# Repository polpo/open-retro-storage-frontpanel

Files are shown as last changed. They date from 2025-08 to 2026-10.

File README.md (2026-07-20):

# Open Retro Storage Front Panel

A physical control and web interface for retro storage emulator projects including [PicoIDE](https://github.com/polpo/picoide) and [BlueSCSI](https://github.com/BlueSCSI/BlueSCSI-v2), based on the ESP32-C3 microcontroller.

PicoIDE variant of the enclosure

BlueSCSI variant of the enclosure

## Overview

The Open Retro Storage Front Panel provides a user-friendly interface for browsing, selecting, and managing drive images for storage emulators live on the device. It features:

- **SPI or I2C (Qwiic) connection to main board**
- **SPI OLED Display**: 128x64 1.3" screen for menu navigation and status display
- **4-Way Navigation**: Physical buttons for browsing drive images and settings
- **WiFi Interface**: Web-based control for changing drive images, adjusting settings, uploading new images, and firmware updates
- **3.5" Drive Bay Enclosure**: Designed for internal or external-facing mounting in standard drive bays

## Project Structure

```
open-retro-storage-frontpanel/
├── sw-frontpanel/       # Firmware source code
├── hw-frontpanel-3.5/   # PCB hardware design
└── enclosure/           # 3D printable enclosure design
```

### sw-frontpanel

ESP32-C3 firmware built with the ESP-IDF SDK (v5.5.1+).

**Features:**
- SPI or I2C (Qwiic) communication with host storage emulator
- Menu system for drive image browsing and selection
- WiFi client and access point modes with mDNS
- Embedded web server with REST API
- OTA firmware updates with SHA256 verification
- WS2812B addressable LED support
- Screen saver, auto-dim, or auto-off to preserve OLED display life

### hw-frontpanel-3.5

KiCad design files for the front panel PCB.

frontpanel-top frontpanel-bottom

**Main components:**
- ESP32-C3-MINI-1 module
- SH1107 1.3" OLED display (SPI interface)
- SK6812MINI-E (WS2812 compatible) addressable RGB LED
- Navigation buttons (either 1-piece silicone rubber dome or plastic button caps w/ individual domes)
- JST-SH connectors for QWIIC/I2C communication with host, external activity LED input, and development debugging, 0.5mm FFC connector for SPI communication with host, and Tag-Connect footprint for initial programming in production

Connector pinouts:

SPI (0.5mm FFC, 12 pin):

| Pin | Function |
|-----|---|
| 1 | Activity LED in |
| 2 | GND |
| 3 | SPI CS |
| 4 | GND |
| 5 | SPI CLK |
| 6 | GND |
| 7 | SPI RX (MISO) |
| 8 | GND |
| 9 | SPI TX (MOSI) |
| 10  | GND |
| 11  | +3.3V |
| 12  | +3.3V |

I2C/Qwiic (JST-SH, 4 pin):

| Pin | Function |
|-----|---|
| 1 | GND|
| 2 | +3.3V |
| 3 | SDA |
| 4 | SCL |

ACT (JST-SH, 2 pin):

| Pin | Function |
|-----|---|
| 1 | Activity LED in |
| 2 | GND |

Production files for JLCPCB assembly are included in `jlcpcb/production_files/`.

### enclosure

FreeCAD design for a 3.5" drive bay enclosure with STEP and STL exports for 3D printing.

**Included parts:**
- Main enclosure body
- Button caps
- Light pipe for activity/status LED
- Silicone button option

## Web Interface

The front panel hosts a web interface accessible at `http://picoide.local` (or via IP address) providing:

- Current drive image status
- Directory browsing
- File upload/download
- Config .ini file editing
- Image selection/ejection
- Firmware status and updates

## Licensing

| Component | License |
|---|---|
| sw-frontpanel | [GPL-2.0-only](sw-frontpanel/LICENSE) |
| hw-frontpanel-3.5 | [CERN-OHL-S-2.0](hw-frontpanel-3.5/LICENSE) |
| enclosure | [CERN-OHL-S-2.0](enclosure/LICENSE) |

## Credits

- Firmware by Ian Scott in collaboration with Eric Helgeson.
- Board design by Ian Scott with input from Jason Merrill.
- Enclosure by Jason Merrill.

## Open source components

- [ESP-IDF](https://github.com/espressif/esp-idf) development framework for ESP32
- [u8g2](https://github.com/olikraus/u8g2) graphics library for OLED
- [u8g2-hal-esp-idf](https://github.com/mkfrey/u8g2-hal-esp-idf) u8g2 HAL layer for ESP-IDF

## Contributing

Contributions are welcome! Please ensure any firmware contributions maintain GPL v2 compatibility and hardware contributions are compatible with CERN-OHL-S v2.

## Building the firmware

Make sure you check out this repository with submodules. If it's already checked out, `git submodule update --init` will fetch them. See [sw-frontpanel/BUILD.md](sw-frontpanel/BUILD.md) for detailed instructions including configuration of target type (PicoIDE/BlueSCSI, SPI/I2C).

## Programming the firmware

For normal firmware upgrades, the front panel can be upgraded via the web interface. But if you're building from scratch or need to recover a bricked unit, you'll need to program the ESP32-C3 by UART bootloader.

There are two footprints on the board that can be used to program it: J4 (prog) and J6 (dbg). J4 is a [Tag-Connect](https://www.tag-connect.com/) footprint, using the [TC2030-IDC-NL](https://www.tag-connect.com/product/tc2030-idc-nl) connector. The pinout matches the 6-pin connector on the [Espressif ESP-PROG 2](https://docs.espressif.com/projects/esp-dev-kits/en/latest/other/esp-prog-2/user_guide.html) programmer:

| Pin | Function |
|-----|---|
| 1 | EN (RTS) |
| 2 | +3.3V |
| 3 | TX |
| 4 | GND |
| 5 | RX |
| 6 | IO0 (DTR) |

J6 is a JST SH 5-pin connector with the following pinout (pins numbered ascending left to right):

| Pin | Function |
|-----|---|
| 1 | GND |
| 2 | RX |
| 3 | TX |
| 4 | EN (RTS) |
| 5 | IO0 (DTR) |

Note that J6 does not carry +3.3V so you'll have to provide it on the SPI or I2C (QWIIC) connector.

Note that the TX signal is shared with the LED input, so if it is driven via the SPI connector programming will not be possible.

Use `esptool` or `esp.py program` to program the firmware after it has been built.

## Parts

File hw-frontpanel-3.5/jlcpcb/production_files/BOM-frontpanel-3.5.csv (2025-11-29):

Comment | Designator | Footprint | LCSC | Quantity
100K | R1 | R_0402_1005Metric | C25741 | 1
100nF | C5,C6 | C_0402_1005Metric | C307331 | 2
100uF | C12 | C_1206_3216Metric | C96123 | 1
10K | R10,R4,R5,R6,R7 | R_0402_1005Metric | C25744 | 5
10uF | C1,C4,C9 | C_0603_1608Metric | C96446 | 3
10uH | L1 | L_0805_2012Metric | C1046 | 1
15K | R2 | R_0402_1005Metric | C25756 | 1
1N5819WS | D2 | D_SOD-323 | C191023 | 1
1uF | C10,C11,C2,C3 | C_0402_1005Metric | C52923 | 4
2.2K | R8,R9 | R_0402_1005Metric | C25879 | 2
33 | R11,R12,R13 | R_0402_1005Metric | C25105 | 3
390K | R3 | R_0402_1005Metric | C25782 | 1
4.7uF | C7,C8 | C_0603_1608Metric | C19666 | 2
ESP32-C3-MINI-1 | U3 | ESP32-C6-MINI-1 | C2838502 | 1
LED | J3 | JST_SH_BM02B-SRSS-TB_1x02-1MP_P1.00mm_Vertical | C7433438 | 1
LM809 | U2 | SOT-23 | C5379074 | 1
MT3540 | U1 | SOT-23-5 | C181744 | 1
QWIIC | J2 | JST_SH_BM04B-SRSS-TB_1x04-1MP_P1.00mm_Vertical | C7433440 | 1
SK6812MINI-E_C5149201 | LED1 | LED-SMD_L3.2-W2.8-LS5.9_SK6812MINI-E | C5149201 | 1
SPI | J1 | FPC-SMD_12P-L11.5-W2.0-P0.50 | C11069 | 1

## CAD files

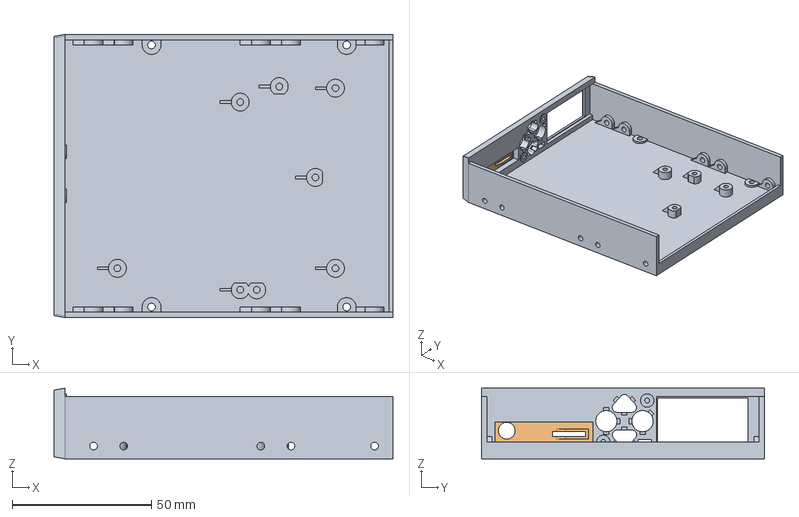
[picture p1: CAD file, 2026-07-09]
enclosure/PicoIDE 3.5 Enclosure.step
121.6 x 101.6 x 25.3 mm
PicoIDE Enclosure
PicoIDE Logo

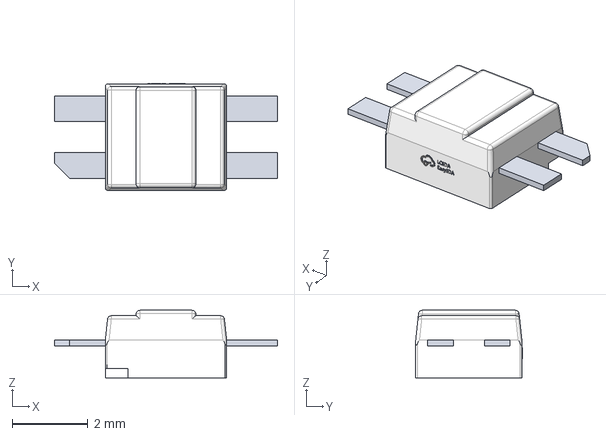
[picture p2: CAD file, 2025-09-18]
hw-frontpanel-3.5/models/LED-SMD_L3.2-W2.8-LS5.9_SK6812MINI-E~LED-SMD_L3.2-W2.8-LS5.9_SK6812MINI-E~0LKI.step
5.88 x 2.81 x 1.78 mm

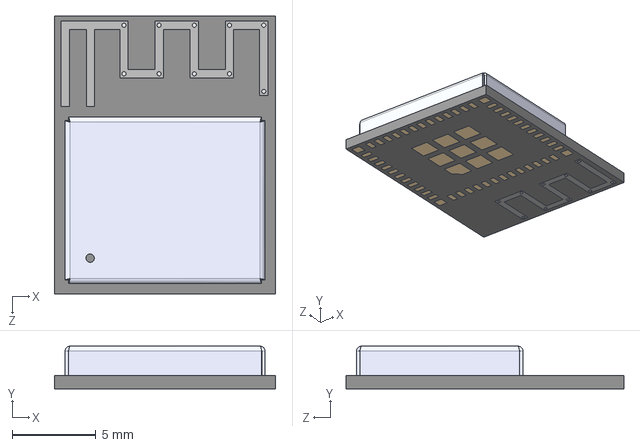
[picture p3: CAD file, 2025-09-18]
hw-frontpanel-3.5/models/ESP32-C6-MINI-1-N4.STEP
13.2 x 2.55 x 16.6 mm

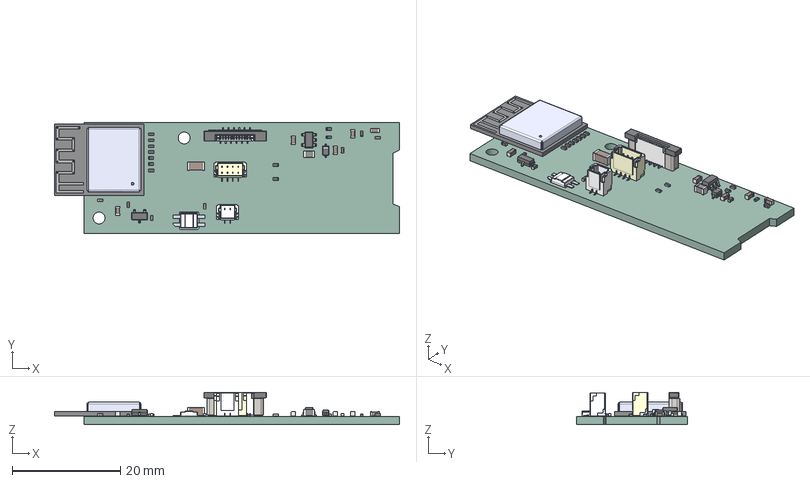
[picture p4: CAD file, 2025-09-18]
hw-frontpanel-3.5/models/frontpanel-3.5-mini.step
63.8 x 20.5 x 5.97 mm
R_0402_1005Metric x 13
LED-SMD_L3.2-W2.8-LS5.9_SK6812MINI-E~LED-SMD_L3.2-W2.8-LS5.9_ SK6812MINI-E~0LKI
C_0402_1005Metric x 5
C_0603_1608Metric x 5
SOT-23-5
D_SOD-323
BM04B-SRSS-TB
L_0805_2012Metric
SOT-23
FPC-SMD_12P-L11.5-W2.0-P0.50~FPC-SMD_12P-L11.6-W2.0-H4.4-P0.50~1kdR
ESP32-C6-MINI-1-N4
C_1206_3216Metric
BMxxB-SRSS-TB(LF)(SN)_02
frontpanel-3.5_PCB

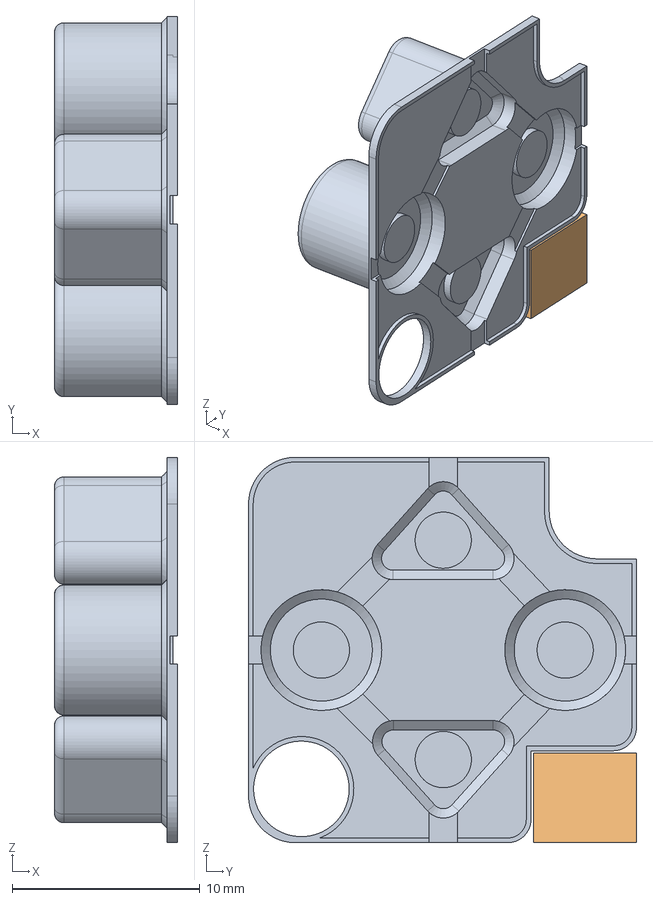
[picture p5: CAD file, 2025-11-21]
enclosure/PicoIDE 3.5 Enclosure-Silicone Buttons.step
6.56 x 20.7 x 20.5 mm

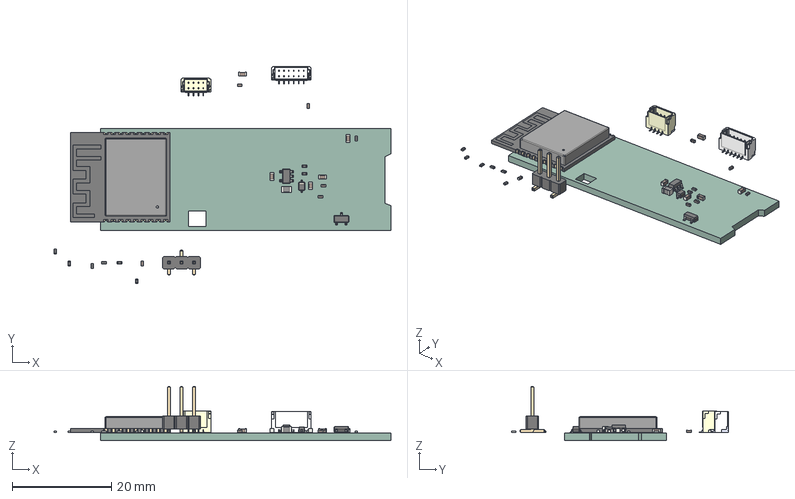
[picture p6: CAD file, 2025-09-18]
hw-frontpanel-3.5/models/frontpanel-3.5-cursed.step
67.8 x 43.8 x 10.9 mm
R_0402_1005Metric x 9
C_0402_1005Metric x 5
C_0603_1608Metric x 5
SOT-23-5
D_SOD-323
BM04B-SRSS-TB
L_0805_2012Metric
SOT-23
BMxxB-SRSS-TB(LF)(SN)_06
ESP32-C3-WROOM-02
PinHeader_1x03_P2.54mm_Vertical_SMD_Pin1Left
frontpanel-3.5_PCB

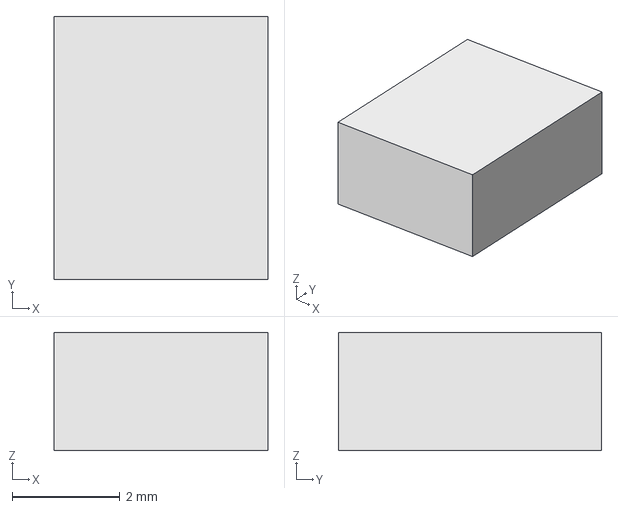
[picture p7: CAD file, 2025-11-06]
enclosure/PicoIDE 3.5 Enclosure-Light Pipe.step
3.98 x 4.90 x 2.20 mm

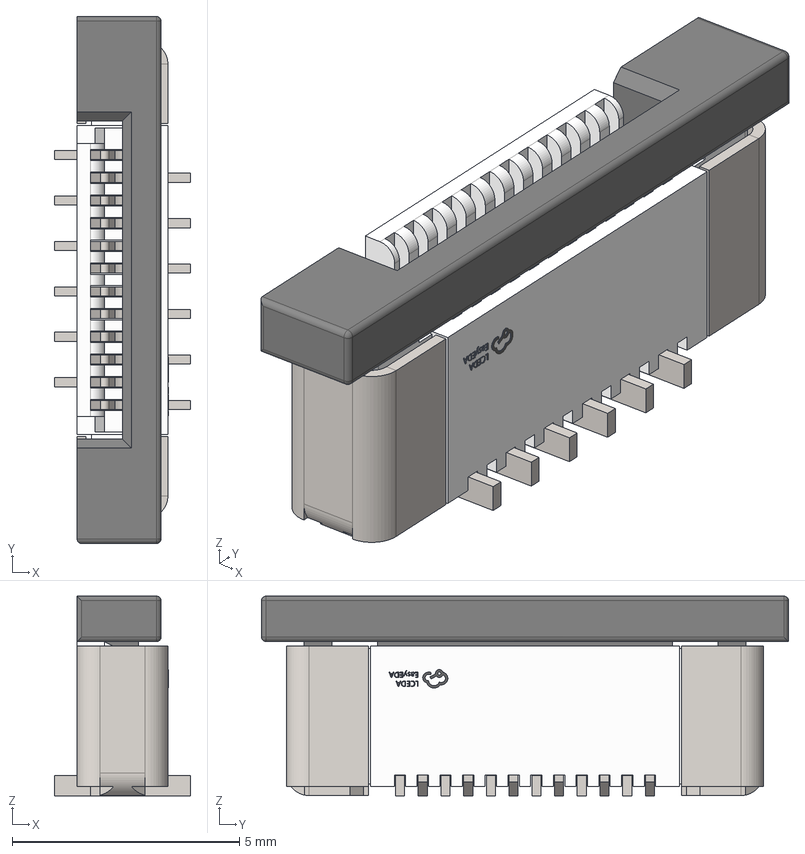
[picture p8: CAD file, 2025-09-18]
hw-frontpanel-3.5/models/AFC11-S12ICC-00.step
3.00 x 11.6 x 4.39 mm

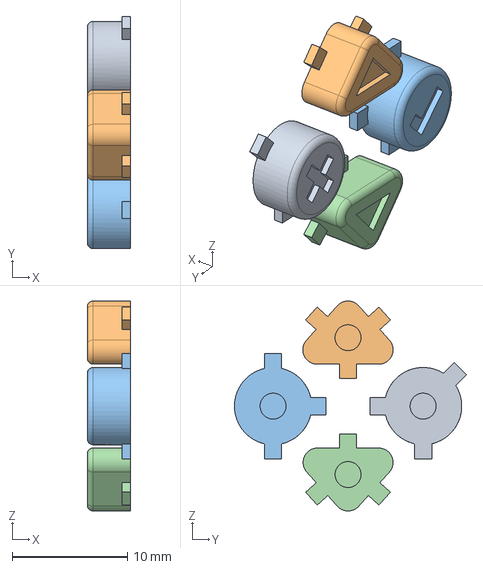
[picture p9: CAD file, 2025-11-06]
enclosure/PicoIDE 3.5 Enclosure-Buttons.step
3.75 x 20.1 x 18.2 mm

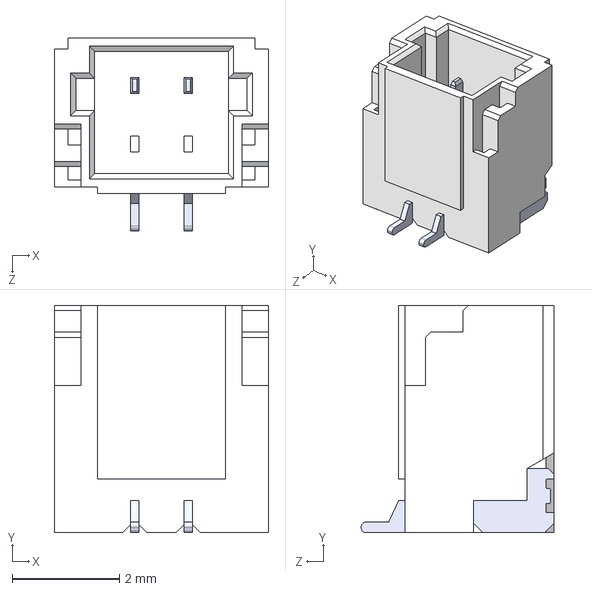
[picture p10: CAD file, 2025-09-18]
hw-frontpanel-3.5/models/BM02B-SRSS-TB.STEP
4.00 x 4.25 x 3.60 mm

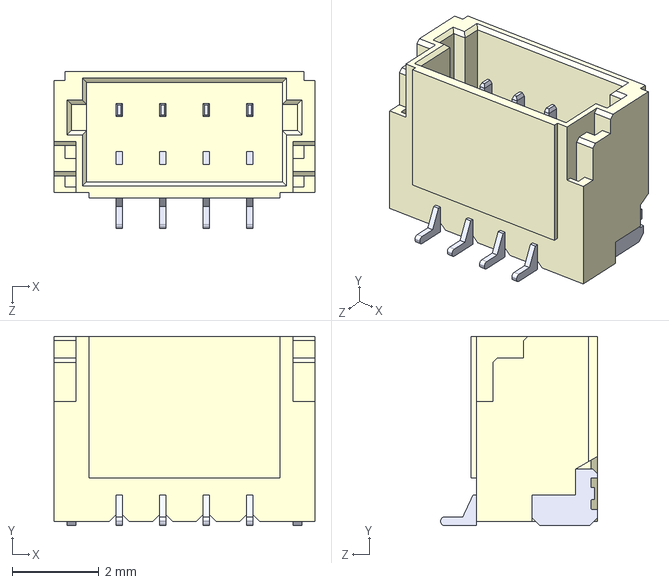
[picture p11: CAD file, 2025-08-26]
hw-frontpanel-3.5/models/BM04B-SRSS-TB.STEP
6.00 x 4.35 x 3.60 mm

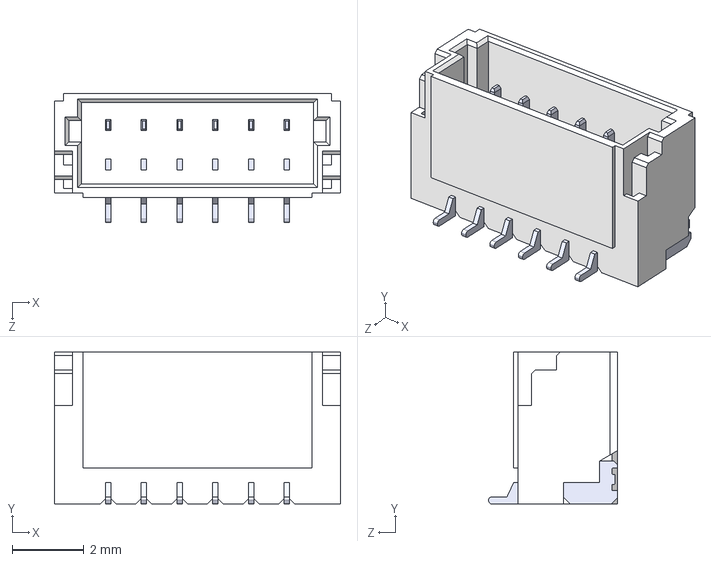
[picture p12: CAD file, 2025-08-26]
hw-frontpanel-3.5/models/BM06B-SRSS-TB.STEP
8.00 x 4.25 x 3.60 mm

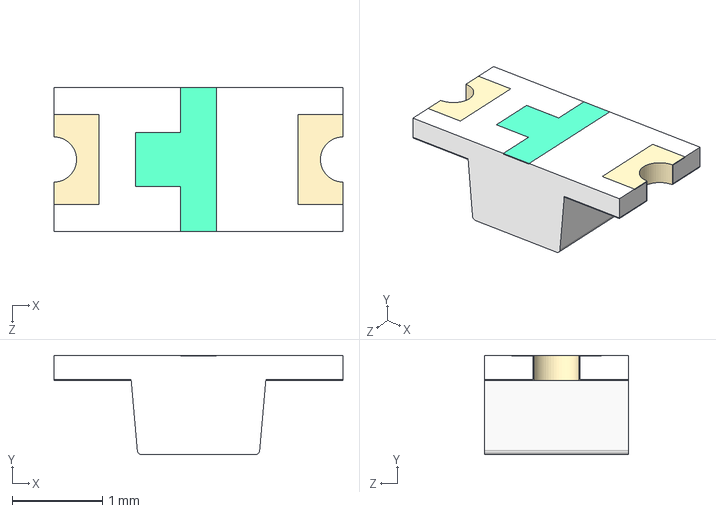
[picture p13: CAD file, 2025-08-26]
hw-frontpanel-3.5/models/LTST-C230KGKT.step
3.20 x 1.10 x 1.60 mm

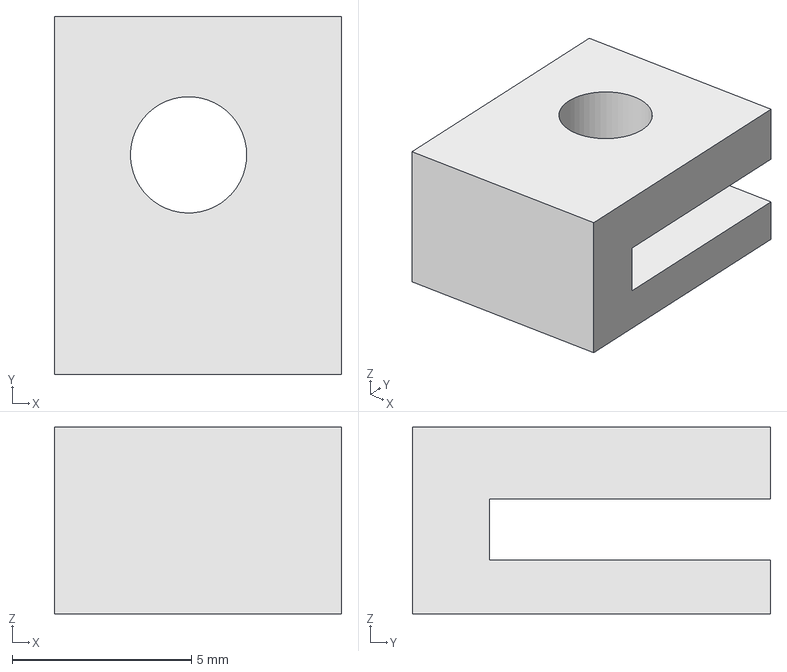
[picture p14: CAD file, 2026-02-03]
enclosure/BlueSCSI Screw Adapter.step
8.00 x 9.99 x 5.21 mm

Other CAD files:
enclosure/BlueSCSI 3.5 Enclosure.step
enclosure/BlueSCSI 3.5 Enclosure.stl
enclosure/BlueSCSI Screw Adapter.stl
enclosure/PicoIDE 3.5 Enclosure-Buttons.stl
enclosure/PicoIDE 3.5 Enclosure-Light Pipe.stl
enclosure/PicoIDE 3.5 Enclosure-Silicone Buttons.stl
enclosure/PicoIDE 3.5 Enclosure.FCStd
enclosure/PicoIDE 3.5 Enclosure.stl

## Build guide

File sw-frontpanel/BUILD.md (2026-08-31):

# Building the firmware

The front-panel firmware targets the ESP32-C3 and is built with ESP-IDF
(v5.5.2). It ships as two product variants — **PicoIDE** and **BlueSCSI** —
selected at configure time via ESP-IDF `sdkconfig` defaults. There is no
interactive `menuconfig` step required to pick the product.

The **host transport** (SPI vs I2C) is detected at runtime on BlueSCSI: one
binary covers **v2** (I2C) and **Ultra / Ultra Wide** (SPI), and the panel
remembers the last transport a live main board answered on in NVS. PicoIDE is
always SPI. For debugging, `menuconfig` can force a single transport
(`HOST_TRANSPORT` choice).

## Development environment

On NixOS / with Nix, a dev shell pins ESP-IDF and the web-asset build
dependencies. Prefix the build commands below with `nix develop --command`,
or enter the shell first:

```bash
nix develop          # flake-based (preferred)
# or: nix-shell       # shell.nix
```

Without Nix, follow the upstream
[ESP-IDF toolchain setup](https://docs.espressif.com/projects/esp-idf/en/stable/esp32c3/get-started/)
and run the same `idf.py` commands.

## Selecting a product

The product is chosen by layering a per-product defaults file on top of the
common `sdkconfig.defaults`:

| Product | Defaults files | Firmware output |
| --- | --- | --- |
| PicoIDE | `sdkconfig.defaults.picoide` | `picoide-frontpanel.bin`  |
| BlueSCSI (v2 / Ultra, one image) | `sdkconfig.defaults.bluescsi`  | `bluescsi-frontpanel.bin` |

Build each product into its **own build directory** (`-B build-<product>`) with
its **own `sdkconfig`** (`-DSDKCONFIG=build-<product>/sdkconfig`). Both flags are
required to keep the products isolated — see the warning below.

> Note: builds prior to the unified BlueSCSI image used
> `build-bluescsi-ultra` / `build-bluescsi-v2` directories. Those pin the old
> transport symbols in their `sdkconfig` — don't reuse them; build into a fresh
> `build-bluescsi`.

### BlueSCSI

```bash
idf.py -B build-bluescsi \
  -DSDKCONFIG=build-bluescsi/sdkconfig \
  -DSDKCONFIG_DEFAULTS="sdkconfig.defaults;sdkconfig.defaults.bluescsi" \
  build
```

Output: `build-bluescsi/bluescsi-frontpanel.bin`

### PicoIDE

```bash
idf.py -B build-picoide \
  -DSDKCONFIG=build-picoide/sdkconfig \
  -DSDKCONFIG_DEFAULTS="sdkconfig.defaults;sdkconfig.defaults.picoide" \
  build
```

Output: `build-picoide/picoide-frontpanel.bin`

## Flashing and monitoring

Replace the port to match your board (e.g. `/dev/ttyACM0`, `/dev/ttyUSB0`):

```bash
idf.py -B build-bluescsi -p /dev/ttyACM0 flash monitor   # BlueSCSI
idf.py -B build-picoide  -p /dev/ttyACM0 flash monitor   # PicoIDE
```

`flash` (re)builds as needed, writes the image, and `monitor` attaches to the
UART. Exit the monitor with `Ctrl-]`.

## Cleaning

```bash
idf.py -B build-bluescsi fullclean    # clean one product's build dir
rm -rf build-bluescsi build-picoide   # or just remove the dirs
```

Run `fullclean` if you change ESP-IDF versions — a build directory configured
against a different IDF Python is rejected on the next build.

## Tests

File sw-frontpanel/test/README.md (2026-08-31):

# Host-native tests

Fast, hardware-free unit tests for the front-panel firmware's protocol and
host-communication layer. They compile a subset of `main/` with the host `gcc`
(no ESP-IDF, no ESP32, no QEMU) against small stubs for the ESP-IDF/FreeRTOS
APIs and a recording **mock transport**, then assert exactly what goes on the
wire.

## Running

```bash
make            # build + run (exit code = number of failed tests)
make build      # build only -> ./runtests
make clean
HOSTTEST_VERBOSE_LOG=1 ...   # (compile-time) echo firmware ESP_LOGx to stderr
```

No dependencies beyond a C11 host compiler and `make`. Also run in CI as the
`host-tests` job (`.github/workflows/build.yml`).

## What's covered

- **`test_protocol_defs.c`** — the `panel_protocol_defs.h` wire contract shared
  with the RP2350 main board: struct sizes, field offsets/packing, little-endian
  header byte layout, command-code direction/async bits, and helper macros.
- **`test_host_comm.c`** — `host_comm.c` command framing, driven through the real
  `transport.c` routing layer into the mock: which command code / argument /
  payload each call emits (signed parent-dir index, the small-vs-extended index
  branch, the `device_index` payload byte, little-endian firmware offsets,
  chunk CRC16), how responses are parsed back (big-endian counts, struct copies),
  and the error paths (timeout, transport error, oversize/!ready responses).

## How the seam works

`host_comm` reaches hardware only through the `transport_ops_t` vtable. The real
`transport.c` factory (`transport_get_ops(transport_type_t)`) returns
`transport_spi_ops` / `transport_i2c_ops` — symbols that `mock_transport.c`
supplies here instead of the real SPI/I2C drivers. So calls route through production code and land in a
mock that records each transaction and replays scripted responses. See
`mock_transport.h` for the scripting API (`mock_set_poll_result`,
`mock_set_xfer_error`, `mock_last_xfer`, …).

## Layout

```
test/
  Makefile               # split flags: firmware lenient, test code -Werror
  test_framework.h       # ~40-line assert/runner (TEST / RUN / CHECK_*)
  test_main.c            # runner; exit code = failed test count
  test_protocol_defs.c   # tier 1: header contract
  test_host_comm.c       # tier 2: command framing via mock
  mock_transport.{h,c}   # recording transport (provides *_ops symbols)
  stubs/                 # minimal host stand-ins for ESP-IDF / FreeRTOS headers
    esp_err.h  esp_log.h  esp_rom_crc.{h,c}
    driver/gpio.h  freertos/{FreeRTOS,semphr,task}.h
```

## Adding a test

1. Write `TEST(my_case) { ... CHECK_*(...); }` in the relevant file.
2. Add `RUN(my_case);` to that file's `run_*_suite()`.
3. New source file → add it to `TEST_OBJS` in the `Makefile` and declare its
   `run_*_suite()` in `test_main.c`.

To cover another `host_comm` call, script the response with `mock_set_poll_result`
(async result) or rely on the default empty-ready, invoke the function, then
assert on `mock_last_xfer()` / `mock_xfer(i)`.

## Scope / caveats

- These test the **panel side** framing and parsing, not a live main board. The
  host `esp_rom_crc16_be` mirrors the CCITT algorithm so chunk-CRC framing is
  exercised, but the ESP32 ROM implementation is authoritative on-device.
- The real SPI/I2C byte transfer (`transport_spi.c` `spi_device_transmit`, DMA,
  the ISR header/payload race) is **not** covered here — that needs on-target or
  QEMU tests. The struct/packing tests do pin the header bytes those drivers move.

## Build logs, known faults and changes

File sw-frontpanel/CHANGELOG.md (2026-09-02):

# v0.5.0

- One BlueSCSI firmware image for all boards: the panel auto-detects the host
  transport (v2 = I2C, Ultra/Ultra Wide = SPI) at boot and remembers it, so
  `bluescsi-frontpanel.bin` replaces the separate `-ultra`/`-v2` images
- Recover the OLED when it misses power-on init (slow 3V3 ramp on host power)
- Show the SD-card panel update path in the BlueSCSI web UI

# v0.4.0

- Add screensavers and configurable idle/blank timeouts
- Combine main board & front panel firmware updates into one operation
- Better reporting of SD card state from main board
- Create releases

# v0.3.0

- Config file editor component
- Better status bar
- Layout improvements
- WiFi status display improvements
- Minification/gzip of static assets for web UI
- Main board comms reliability improvements

# v0.2.2

- Fix display glitch on firmware update screen

# v0.2.1

- Fix menu scrolling on menus that barely go off the screen

# v0.2.0

- Better display of main/front panel FW versions
- Fix for keypress to wake up display passing through as event
- Better handling of image status, handle fixed HDDs on status screen

# v0.1.0

- Initial beta release

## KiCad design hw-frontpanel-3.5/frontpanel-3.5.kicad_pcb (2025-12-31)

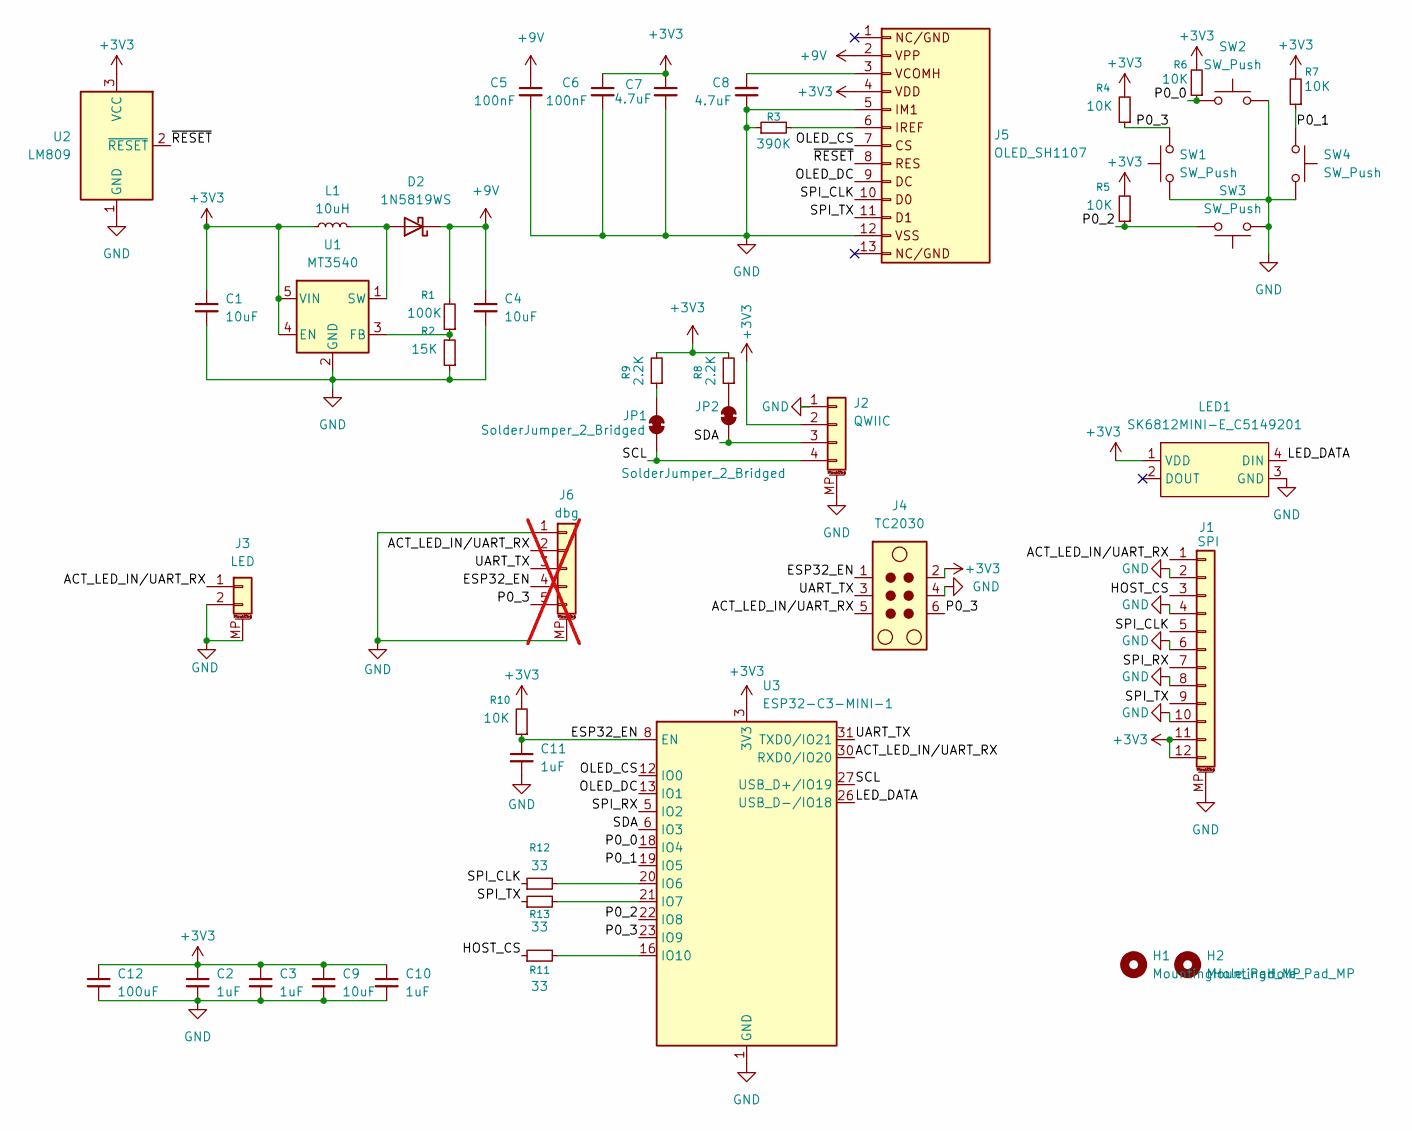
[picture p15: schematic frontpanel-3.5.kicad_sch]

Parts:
C1, C4: 10uF; C_0603_1608Metric; LCSC C96446
C2, C3, C10, C11: 1uF; C_0402_1005Metric; LCSC C15849
C5, C6: 100nF; C_0402_1005Metric; LCSC C14663
C7, C8: 4.7uF; C_0603_1608Metric; LCSC C19666
C9: 10uF; C_0603_1608Metric
C12: 100uF; C_1206_3216Metric; LCSC C96123
D2: 1N5819WS; D_SOD-323; LCSC C191023
H1, H2: MountingHole_Pad_MP; MountingHole_2.2mm_M2
J1: SPI; FPC-SMD_12P-L11.5-W2.0-P0.50; LCSC C2874482
J2: QWIIC; JST_SH_BM04B-SRSS-TB_1x04-1MP_P1.00mm_Vertical; LCSC C23390346
J3: LED; JST_SH_BM02B-SRSS-TB_1x02-1MP_P1.00mm_Vertical; LCSC C22438427
J4: TC2030; Tag-Connect_TC2030-IDC-NL_2x03_P1.27mm_Vertical
J5: OLED_SH1107; OLED-SMD_N130-6428TSWOG01-H13
J6: dbg; JST_SH_BM05B-SRSS-TB_1x05-1MP_P1.00mm_Vertical; LCSC C22438427; not fitted
JP1, JP2: SolderJumper_2_Bridged; SolderJumper-2_P1.3mm_Bridged_RoundedPad1.0x1.5mm
L1: 10uH; L_0805_2012Metric; LCSC C1046
LED1: SK6812MINI-E_C5149201; LED-SMD_L3.2-W2.8-LS5.9_SK6812MINI-E; LCSC Part C5149201
R1: 100K; R_0402_1005Metric; LCSC C25803
R2: 15K; R_0402_1005Metric; LCSC C22809
R3: 390K; R_0402_1005Metric; LCSC C23150
R4, R5, R6, R7, R10: 10K; R_0402_1005Metric; LCSC C25804
R8, R9: 2.2K; R_0402_1005Metric; LCSC C4190
R11, R12, R13: 33; R_0402_1005Metric
SW1, SW2, SW3, SW4: SW_Push; button-contact-round-5mm
U1: MT3540; SOT-23-5; LCSC C181744
U2: LM809; SOT-23; LCSC C5379074
U3: ESP32-C3-MINI-1; ESP32-C6-MINI-1; LCSC C2838502

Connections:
+3V3: C1.1, C2.1, C3.1, C6.1, C7.1, C9.1, C10.1, C12.1, J1.11, J1.12, J2.2, J4.2, J5.4, L1.1, LED1.1 (VDD), R4.2, R5.2, R6.2, R7.2, R8.2, R9.2, R10.2, U1.4 (EN), U1.5 (VIN), U2.3 (VCC), U3.3 (3V3)
+9V: C4.1, C5.1, D2.1 (K), J5.2, R1.2
/ACT_LED_IN/UART_RX: J1.1, J3.1, J4.5, J6.2, U3.30 (RXD0/IO20)
/ESP32_EN: C11.1, J4.1, J6.4, R10.1, U3.8 (EN)
/HOST_CS: J1.3, R11.1
/LED_DATA: LED1.4 (DIN), U3.26 (USB_D-/IO18)
/OLED_CS: J5.7, U3.12 (IO0)
/OLED_DC: J5.9, U3.13 (IO1)
/P0_0: R6.1, SW2.1, U3.18 (IO4)
/P0_1: R7.1, SW4.1, U3.19 (IO5)
/P0_2: R5.1, SW3.2, U3.22 (IO8)
/P0_3: J4.6, J6.5, R4.1, SW1.2, U3.23 (IO9)
/SCL: J2.4, JP1.1 (A), U3.27 (USB_D+/IO19)
/SDA: J2.3, JP2.1 (A), U3.6 (IO3)
/SPI_CLK: J1.5, J5.10, R12.1
/SPI_RX: J1.7, U3.5 (IO2)
/SPI_TX: J1.9, J5.11, R13.1
/UART_TX: J4.3, J6.3, U3.31 (TXD0/IO21)
/~RESET: J5.8, U2.2 (~RESET)
GND: C1.2, C2.2, C3.2, C4.2, C5.2, C6.2, C7.2, C8.1, C9.2, C10.2, C11.2, C12.2, J1.2, J1.4, J1.6, J1.8, J1.10, J1.MP (MountPin), J2.1, J2.MP (MountPin), J3.2, J3.MP (MountPin), J4.4, J5.5, J5.12, J6.1, J6.MP (MountPin), LED1.3 (GND), R2.1, R3.1, SW1.1, SW2.2, SW3.1, SW4.2, U1.2 (GND), U2.1 (GND), U3.1 (GND), U3.2 (GND), U3.11 (GND), U3.14 (GND), U3.36 (GND), U3.37 (GND), U3.38 (GND), U3.39 (GND), U3.40 (GND), U3.41 (GND), U3.42 (GND), U3.43 (GND), U3.44 (GND), U3.45 (GND), U3.46 (GND), U3.47 (GND), U3.48 (GND), U3.49 (GND), U3.50 (GND), U3.51 (GND), U3.52 (GND), U3.53 (GND)
unnamed: D2.2 (A), L1.2, U1.1 (SW)
unnamed: C8.2, J5.3
unnamed: J5.6, R3.2
unnamed: JP1.2 (B), R9.1
unnamed: JP2.2 (B), R8.1
unnamed: R1.1, R2.2, U1.3 (FB)
unnamed: R12.2, U3.20 (IO6)
unnamed: R13.2, U3.21 (IO7)
unnamed: R11.2, U3.16 (IO10)

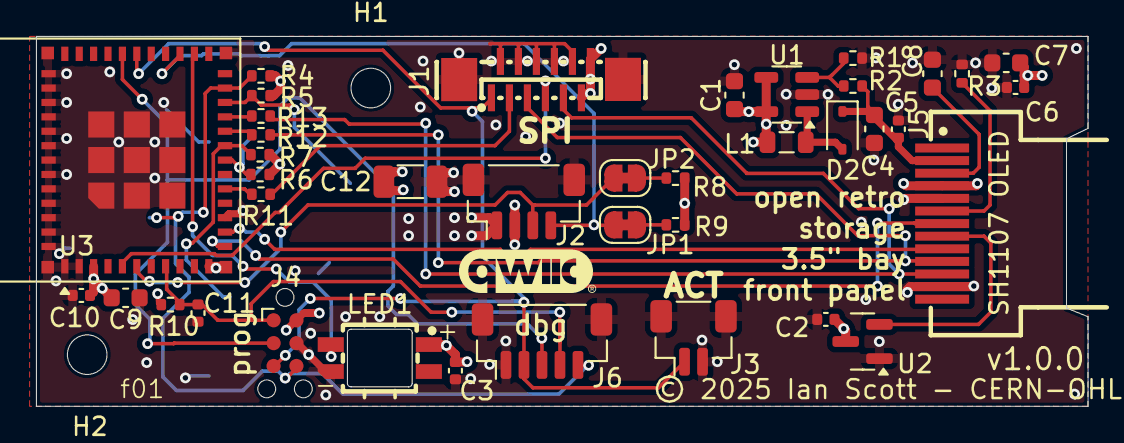
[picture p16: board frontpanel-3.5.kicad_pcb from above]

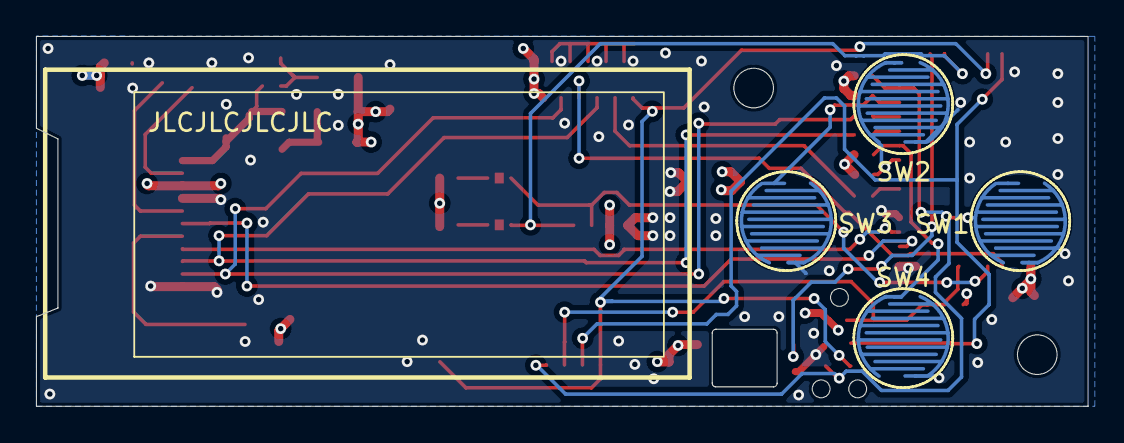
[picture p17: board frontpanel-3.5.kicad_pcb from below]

Board: 4 copper layers, 58.4 x 20.5 mm, 45 parts (4 on the bottom side), 29 nets.

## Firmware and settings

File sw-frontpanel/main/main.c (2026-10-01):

// SPDX-License-Identifier: GPL-2.0-only
//
//  Copyright (C) 2025  Ian Scott
//
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
#include <stdio.h>
#include <string.h>
#include "freertos/FreeRTOS.h"
#include "freertos/task.h"
#include "esp_log.h"
#include "esp_system.h"
#include "driver/spi_master.h"

#include "gpio_pins.h"
#include "gpio_handler.h"
#include "display_manager.h"
#include "menu_system.h"
#include "host_comm.h"  // Modular transport layer (I2C/SPI)
#include "host_link.h"  // Per-transport config + persisted transport type
#include "transport_config.h" // Transport configuration
#include "ui_screens.h"
#include "led_driver.h"
#include "wifi_manager.h"
#include "web_server.h"
#include "interface_common.h"
#include "panel_policy.h"
#include "esp_netif_ip_addr.h"
#include "ota_manager.h"
#include "fw_version.h"
#include "driver/gpio.h"
#include "freertos/queue.h"
#include "nvs_flash.h"
#include "test_hooks.h"

static const char *TAG = "main";

// Main board may be held in reset for several seconds after power-on. Wait
// this long for it at startup before booting in degraded mode; a background
// probe keeps trying afterward so the panel recovers whenever it appears.
#define HOST_COMM_STARTUP_TIMEOUT_MS  20000
#define HOST_COMM_RETRY_INTERVAL_MS   500

#ifdef CONFIG_HOST_TRANSPORT_AUTO
// Auto-detect: give the NVS-saved transport this much of the startup window
// to itself before alternating both transports (covers a panel moved between
// board types without probing the other bus on every normal boot).
#define HOST_LINK_SAVED_EXCLUSIVE_MS  10000
// Background probe cadence once boot detection has given up. Backs off from
// MIN to MAX: every probe installs and removes a bus driver, and the SPI one
// shares SPI2_HOST with the OLED, so a panel left with no main board attached
// must not churn the display's bus once a second forever.
#define HOST_LINK_PROBE_MIN_MS        1000
#define HOST_LINK_PROBE_MAX_MS        30000
#endif

// OLED startup recovery. When the panel is powered only from the host (no USB),
// the +3V3 rail ramps slowly enough that the display's hardware reset (LM809)
// can release — and its +9V VPP boost stabilize — after display_manager_init()
// has already run its one-shot init, leaving the OLED dark. Re-assert the init
// a few times over the first few seconds; harmless once the panel is up.
#define DISPLAY_STARTUP_REINIT_FIRST_MS     2000
#define DISPLAY_STARTUP_REINIT_INTERVAL_MS  500
#define DISPLAY_STARTUP_REINIT_COUNT        3

// Global instances
static display_manager_t display;
static menu_t main_menu;
static menu_t disc_menu;
static menu_t wifi_menu;
static menu_t settings_menu;
static menu_t device_menu;
static menu_t display_settings_menu;  // Parent: Idle Mode / Idle Timeout / Blank Timeout
static menu_t idle_mode_menu;
static menu_t idle_timeout_menu;
static menu_t blank_timeout_menu;
static menu_t *active_menu = NULL;  // Pointer to currently displayed menu
static screen_type_t info_return_screen = SCREEN_MAIN_MENU;  // Screen to return to from SCREEN_INFO

// Menu lookup by screen type (screens without menus are NULL)
static menu_t* screen_menus[SCREEN_COUNT] = {
    [SCREEN_MAIN_MENU] = &main_menu,
    [SCREEN_DISC_LIST] = &disc_menu,
    [SCREEN_SETTINGS] = &settings_menu,
    [SCREEN_WIFI_MENU] = &wifi_menu,
    [SCREEN_DEVICE_SELECT] = &device_menu,
    [SCREEN_DISPLAY_SETTINGS] = &display_settings_menu,
    [SCREEN_IDLE_MODE] = &idle_mode_menu,
    [SCREEN_IDLE_TIMEOUT] = &idle_timeout_menu,
    [SCREEN_BLANK_TIMEOUT] = &blank_timeout_menu,
#ifdef CONFIG_PRODUCT_BLUESCSI
    [SCREEN_INITIATOR_STATUS] = NULL,
#endif
};
static host_comm_t host_comm;
static bool host_comm_ready = false;  // True once the transport layer is up (host_comm_init succeeded)
#ifdef CONFIG_HOST_TRANSPORT_AUTO
static bool auto_link_pending = false;  // Boot detection found no main board; keep probing in the background
static host_comm_t probe_comm;  // Scratch handle for background probes; the shared host_comm
                                // (and its mutex) must never be torn down once handlers can see it
#endif
static wifi_manager_t wifi_manager;
static web_server_t web_server;
static interface_context_t interface_ctx;
static screen_type_t current_screen = SCREEN_SPLASH;
static ota_manager_t ota_manager;

// Dynamic disc list - populated from I2C communication
static bool disc_list_loaded = false;
static char current_disc_name[64] = "";
static playback_status_t current_playback_status = {0};
static bool disc_name_changed = true;  // Flag to signal title changed (resets scroll)
static bool status_needs_redraw = true;  // Flag to signal status screen needs redraw
static loaded_image_status_t current_image_status = {0};  // Full image status including directory

// Device type (IDE vs ATAPI) - affects available operations
static uint8_t current_device_type = PANEL_DEVICE_TYPE_ATAPI;  // Default to ATAPI

// Multi-device support
static uint8_t device_count = 0;
static uint16_t active_device_index = 0;
static uint8_t device_list_buffer[sizeof(device_list_response_t) + CONFIG_MAX_DEVICES * sizeof(device_summary_t)];
static device_list_response_t *device_list = (device_list_response_t *)device_list_buffer;
static bool device_list_valid = false;
// A main board that fails GET_DEVICE_LIST fails it every time, so re-asking on
// every status poll costs a host transaction and a warning every few seconds
// forever. Back off instead, and warn only on the first failure of a run.
#define DEVICE_LIST_RETRY_MS 30000
static bool device_list_failed = false;
static TickType_t device_list_next_try = 0;

// Latest PANEL_CMD_GET_DEVICE_STATUS reply, refreshed alongside playback
// status. Drives the LED color so SD error states (NO_CARD, WRONG_MODE) get
// distinct indication beyond just "no disc."
static uint8_t current_device_status = PANEL_DEVICE_STATUS_NO_IMAGE;

// Firmware status tracking
static rp2350_fw_status_t rp2350_fw_status = {0};
static panel_firmware_info_t panel_fw_info = {0};
static bool fw_status_valid = false;
#ifdef CONFIG_PRODUCT_BLUESCSI
static uint8_t fw_screen_selection = 0;  // 0=Panel, 1=Main board
#endif

// Forward declarations
static esp_err_t refresh_directory_list(void);
static void refresh_playback_status(void);
static void refresh_device_type(void);

// Web handlers change the directory (or its contents) without going through the
// panel's menus, so they invalidate the cache here and the browser reloads on
// its next open.
void interface_invalidate_disc_list(void) {
    disc_list_loaded = false;
}
static void refresh_device_list(void);
static bool select_default_device(void);
static bool active_device_is_removable(void);
static void rebuild_main_menu(void);
static void populate_device_menu(void);
static void on_host_link_established(void);
static const char* get_active_device_label(void);
static void check_firmware_status(void);
static void draw_firmware_status_screen(void);
#ifdef CONFIG_PRODUCT_BLUESCSI
static void trigger_panel_update(void);
static void trigger_mainboard_update(void);
#else
static void trigger_system_update(void);
#endif
static void reconnect_to_host(void);
static bool handle_comm_error(esp_err_t err);
static void show_info_screen(const char *title, const char *body);
static void redraw_current_screen(void);
#ifdef CONFIG_PANEL_TEST_HOOKS
static void panel_publish_ui_state(void);
static void panel_publish_framebuffer(void);
#endif

// SCREEN_INFO state. Title is always a string literal (caller-owned). Body is
// often built on the caller's stack, so we copy it so the screen survives
// being re-rendered later (e.g. after the screensaver clears the buffer).
static const char *info_screen_title = "";
static char info_screen_body[256] = "";
static uint32_t info_screen_scroll = 0;  // First visible wrapped line of info_screen_body

// Cached state used to refresh the LED both on activity events and on display
// off-state transitions so breathing can pick up the current color
static activity_event_t last_activity_event = {0};
static bool display_is_off = false;

#ifdef CONFIG_PRODUCT_BLUESCSI
// Initiator (disk imaging) mode. The main board reports the mode in the device
// list; while it is imaging there are no emulated devices to browse.
static uint8_t operating_mode = PANEL_MODE_TARGET;
static uint8_t initiator_status_buffer[sizeof(initiator_status_response_t) +
                                       8 * sizeof(initiator_target_info_t)];
static initiator_status_response_t *initiator_status =
    (initiator_status_response_t *)initiator_status_buffer;
static int  initiator_target_count = 0;
static bool initiator_status_needs_redraw = true;
// Progress of the run, from PANEL_CMD_GET_INITIATOR_SUMMARY. That is a
// synchronous read the main board answers from its ISR, so it arrives while the
// board is imaging - which is exactly when the async GET_INITIATOR_STATUS, and
// so the per-target detail, does not.
static panel_initiator_summary_t initiator_summary;
static void refresh_initiator_status(void);

bool panel_in_initiator_mode(void) { return operating_mode == PANEL_MODE_INITIATOR; }
const panel_initiator_summary_t *panel_get_initiator_summary(void) {
    return &initiator_summary;
}
const initiator_status_response_t *panel_get_initiator_status(int *target_count) {
    if (target_count) *target_count = initiator_target_count;
    return initiator_status;
}
#endif

// Computes the LED color implied by current state. Returns true via the
// out-param when the color represents in-progress disc activity, which
// suppresses the slow breathe so reads/writes remain clearly visible
static rgb_color_t compute_led_state_color(bool *is_activity) {
    *is_activity = false;
#ifdef CONFIG_PRODUCT_BLUESCSI
    // Checked before the SD-card states below, which BlueSCSI never reports.
    if (operating_mode == PANEL_MODE_INITIATOR) {
        switch (initiator_status->phase) {
            case PANEL_INITIATOR_PHASE_IMAGING:
                // The main board blinks its status LED in proportion to imaging
                // progress and that line drives PIN_ACT_IN, so following the pin
                // here makes the panel blink with real SCSI reads. is_activity
                // also suppresses the idle breathe.
                *is_activity = true;
                return last_activity_event.pin_state ? COLOR_GREEN : COLOR_OFF;
            case PANEL_INITIATOR_PHASE_COMPLETE: return COLOR_BLUE;
            case PANEL_INITIATOR_PHASE_ERROR:    return COLOR_RED;
            default:                             return COLOR_CYAN;  // scanning
        }
    }
#endif
    // SD-card error states win over the normal disc-inserted check so the
    // user sees a clearly different color than the generic "no image" idle
    switch (current_device_status) {
        case PANEL_DEVICE_STATUS_NO_CARD:
            return COLOR_RED;
        case PANEL_DEVICE_STATUS_WRONG_MODE:
            return COLOR_MAGENTA;
        default:
            break;
    }
    if (!(current_playback_status.flags & PANEL_PB_DISC_INSERTED)) {
        return COLOR_ORANGE;  // No image loaded
    }
    if (last_activity_event.pin_state) {
        *is_activity = true;
        return COLOR_YELLOW;  // Activity
    }
    return COLOR_CYAN;        // Idle with image
}

// Re-applies the LED color and breathe state from current cached state.
// Safe to call whenever device status, playback status, last activity event,
// or display-off state changes
static void refresh_led_state(void) {
    bool is_activity;
    rgb_color_t color = compute_led_state_color(&is_activity);

    if (display_is_off && !is_activity) {
        led_set_color(color);     // updates cache; breathe task picks up
        led_start_breathe();      // idempotent
    } else {
        led_stop_breathe();       // idempotent
        led_set_color(color);
    }
}

// Activity LED handler
static void handle_activity_event(activity_event_t *event) {
    if (!event) return;
    last_activity_event = *event;
    refresh_led_state();
}

static void on_display_off_state_change(bool now_off, void *ctx) {
    (void)ctx;
    display_is_off = now_off;
    refresh_led_state();
}

// Main menu contents depend on the state of the board we're controlling: "Eject
// Image" only if the current device has removable media, and "Select Device"
// only when there is more than one device. main_menu_layout() in panel_policy.c
// decides that; rebuild_main_menu() renders it. Every row starts absent so a
// button arriving before the first rebuild cannot alias row 0.
static menu_item_t main_menu_items[MAIN_MENU_MAX_ITEMS];
static main_menu_layout_t main_menu_rows = {
    .count = 0,
    .position = { -1, -1, -1, -1, -1 },
};

static menu_item_t settings_menu_items[] = {
    {.text = "Firmware Update", .action = MENU_ACTION_CUSTOM, .selectable = true},
    {.text = "WiFi", .action = MENU_ACTION_CUSTOM, .selectable = true},
    {.text = "Display Settings", .action = MENU_ACTION_CUSTOM, .selectable = true},
};

static menu_item_t wifi_menu_items[] = {
    {.text = "WiFi Status", .action = MENU_ACTION_CUSTOM, .selectable = true},
    {.text = "Reset WiFi", .action = MENU_ACTION_CUSTOM, .selectable = true},
};
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
void app_main(void) {
    ESP_LOGI(TAG, "%s Starting...", PRODUCT_NAME_FULL);

    // NVS must be ready before display_manager_init loads its idle-mode/timeout
    // config. wifi_manager_init also calls nvs_flash_init later, but that's
    // idempotent.
    esp_err_t nvs_ret = nvs_flash_init();
    if (nvs_ret == ESP_ERR_NVS_NO_FREE_PAGES || nvs_ret == ESP_ERR_NVS_NEW_VERSION_FOUND) {
        ESP_ERROR_CHECK(nvs_flash_erase());
        nvs_ret = nvs_flash_init();
    }
    ESP_ERROR_CHECK(nvs_ret);

    // Initialize shared SPI bus with MISO enabled for host communication
    spi_bus_config_t bus_config = {
        .mosi_io_num = PIN_SPI_MOSI,
        .miso_io_num = PIN_SPI_MISO,
        .sclk_io_num = PIN_SPI_CLK,
        .quadwp_io_num = GPIO_NUM_NC,
        .quadhd_io_num = GPIO_NUM_NC,
        .max_transfer_sz = 4096,
    };

    esp_err_t ret = spi_bus_initialize(SPI2_HOST, &bus_config, SPI_DMA_CH_AUTO);
    if (ret != ESP_OK) {
        ESP_LOGE(TAG, "Failed to initialize shared SPI bus: %s", esp_err_to_name(ret));
        return;
    }
    ESP_LOGI(TAG, "Shared SPI bus initialized (MISO: %d, MOSI: %d, CLK: %d)",
             PIN_SPI_MISO, PIN_SPI_MOSI, PIN_SPI_CLK);

    ret = display_manager_init(&display);
    if (ret != ESP_OK) {
        ESP_LOGE(TAG, "Failed to initialize display: %s", esp_err_to_name(ret));
        return;
    }

    xTaskCreate(display_update_task, "display_update", 2048, NULL, 5, NULL);
    xTaskCreate(status_refresh_task, "status_refresh", 2048, NULL, 4, NULL);

    ui_show_splash_screen(&display);
    ui_update_splash_progress(&display, "Init display...", 10);

    ui_update_splash_progress(&display, "Init LED...", 20);
    ret = led_driver_init();
    if (ret != ESP_OK) {
        ESP_LOGE(TAG, "Failed to initialize LED driver: %s", esp_err_to_name(ret));
        return;
    }
    led_start_pulse(COLOR_CYAN);

    ui_update_splash_progress(&display, "Init GPIO...", 30);
    ret = gpio_handler_init();
    if (ret != ESP_OK) {
        ESP_LOGE(TAG, "Failed to initialize gpio handler: %s", esp_err_to_name(ret));
        return;
    }

    ret = gpio_handler_configure_activity_pin(PIN_ACT_IN);
    if (ret != ESP_OK) {
        ESP_LOGE(TAG, "Failed to configure activity pin: %s", esp_err_to_name(ret));
        return;
    }

    ret = gpio_handler_install_activity_isr(PIN_ACT_IN);
    if (ret != ESP_OK) {
        ESP_LOGE(TAG, "Failed to install activity ISR: %s", esp_err_to_name(ret));
        return;
    }

    // Register custom activity handler for LED control
    gpio_handler_register_activity_callback(handle_activity_event);

    // Set initial LED to orange (no image loaded yet)
    led_set_color(COLOR_ORANGE);
    
    ui_update_splash_progress(&display, "Init buttons...", 40);
    // Configure buttons with repeat for up/down navigation
    button_config_t nav_button_config = {
        .active_low = true,
        .enable_double_click = false,
        .enable_long_press = true,
        .enable_repeat = true,
        .debounce_ms = 100,
        .double_click_ms = 300,
        .long_press_ms = 300,  // Start repeating after 300ms
        .repeat_ms = 80        // Repeat every 80ms
    };
    
    // Configure buttons without repeat for select/back
    button_config_t action_button_config = {
        .active_low = true,
        .enable_double_click = false,
        .enable_long_press = false,
        .enable_repeat = false,
        .debounce_ms = 100,
        .double_click_ms = 300,
        .long_press_ms = 1000,
        .repeat_ms = 100
    };
    
    nav_button_config.gpio = PIN_NAV_UP;
    gpio_handler_add_button(0, &nav_button_config);

    nav_button_config.gpio = PIN_NAV_DOWN;
    gpio_handler_add_button(2, &nav_button_config);

    action_button_config.gpio = PIN_NAV_RIGHT;
    gpio_handler_add_button(1, &action_button_config);

    action_button_config.gpio = PIN_NAV_LEFT;
    gpio_handler_add_button(3, &action_button_config);

    gpio_handler_register_button_callback(handle_button_event);
    gpio_handler_start();

    ui_update_splash_progress(&display, "Init menus...", 50);
    menu_init(&main_menu, MENU_VISIBLE_ITEMS_WITH_TITLE);
    main_menu.title = "Main Menu";
    rebuild_main_menu();

    menu_init(&disc_menu, MENU_VISIBLE_ITEMS_WITH_TITLE);
    disc_menu.title = "Select Image";

    menu_init(&settings_menu, MENU_VISIBLE_ITEMS_WITH_TITLE);
    settings_menu.title = "Settings";
    menu_set_items(&settings_menu, settings_menu_items,
                  sizeof(settings_menu_items) / sizeof(settings_menu_items[0]));

    menu_init(&wifi_menu, MENU_VISIBLE_ITEMS_WITH_TITLE);
    wifi_menu.title = "WiFi Setup";
    menu_set_items(&wifi_menu, wifi_menu_items,
                  sizeof(wifi_menu_items) / sizeof(wifi_menu_items[0]));

    menu_init(&device_menu, MENU_VISIBLE_ITEMS_WITH_TITLE);
    device_menu.title = "Select Device";

    menu_init(&display_settings_menu, MENU_VISIBLE_ITEMS_WITH_TITLE);
    display_settings_menu.title = "Display";
    menu_set_items(&display_settings_menu, display_settings_menu_items,
                  sizeof(display_settings_menu_items) / sizeof(display_settings_menu_items[0]));

    menu_init(&idle_mode_menu, MENU_VISIBLE_ITEMS_WITH_TITLE);
    idle_mode_menu.title = "Idle Mode";
    menu_set_items(&idle_mode_menu, idle_mode_menu_items,
                  sizeof(idle_mode_menu_items) / sizeof(idle_mode_menu_items[0]));

    menu_init(&idle_timeout_menu, MENU_VISIBLE_ITEMS_WITH_TITLE);
    idle_timeout_menu.title = "Idle Timeout";
    menu_set_items(&idle_timeout_menu, idle_timeout_menu_items, IDLE_TIMEOUT_OPTION_COUNT);

    menu_init(&blank_timeout_menu, MENU_VISIBLE_ITEMS_WITH_TITLE);
    blank_timeout_menu.title = "Blank Timeout";
    menu_set_items(&blank_timeout_menu, blank_timeout_menu_items, BLANK_TIMEOUT_OPTION_COUNT);

    display_manager_set_off_state_callback(&display, on_display_off_state_change, NULL);

    ui_update_splash_progress(&display, "Establish comms...", 55);
    ESP_LOGI(TAG, "Waiting %d ms for main board startup...", HOST_STARTUP_DELAY_MS);
    vTaskDelay(pdMS_TO_TICKS(HOST_STARTUP_DELAY_MS));

    esp_err_t comm_ret = establish_host_link();
    {
#ifdef CONFIG_HOST_TRANSPORT_AUTO
        // Detection exhausted the window with no live board on either
        // transport; keep probing from status_refresh_task.
        bool board_missing = (comm_ret != ESP_OK);
        auto_link_pending = board_missing;
#else
        // Transport up but board silent. (If host_comm_init itself failed,
        // there is nothing to probe and no blink, as before.)
        bool board_missing = (comm_ret != ESP_OK) && host_comm_ready;
#endif
        if (board_missing) {
            ESP_LOGE(TAG, "Failed to communicate with main board: %s", esp_err_to_name(comm_ret));
            led_stop_pulse();

            for (int i = 0; i < 6; i++) {
                led_set_color(COLOR_RED);
                vTaskDelay(pdMS_TO_TICKS(200));
                led_clear();
                vTaskDelay(pdMS_TO_TICKS(200));
            }

            if (host_comm_ready) {
                host_comm.link_up = false;
            }
        }
        if (comm_ret == ESP_OK) {
            ESP_LOGI(TAG, "Communication with main board verified");

            // Get and display main board firmware version
            rp2350_fw_status_t fw_status;
            if (host_comm_get_rp2350_fw_status(&host_comm, &fw_status) == ESP_OK) {
                char main_version[20];
                fw_version_format_mainboard(main_version, sizeof(main_version), fw_status.current_version);
                ui_update_splash_version(&display, main_version);
                ESP_LOGI(TAG, "Main board firmware version: %s", main_version);
            }

            // Get device list for multi-device support
            refresh_device_list();

            // Default the panel to the first removable device (e.g. CD-ROM)
            // rather than device 0, which is often a fixed HDD or a
            // non-removable device like a network adapter.
            select_default_device();

            // Get device type of the device we settled on
            refresh_device_type();

            if (device_count > 1) {
                ESP_LOGI(TAG, "Multi-device mode: %u devices", device_count);
            }

            ESP_LOGI(TAG, "Fetching directory list at startup...");
            ui_update_splash_progress(&display, "Load directory...", 70);
            esp_err_t disc_ret = refresh_directory_list();
            if (disc_ret == ESP_OK) {
                ESP_LOGI(TAG, "Directory list loaded successfully at startup");
            } else {
                ESP_LOGW(TAG, "Failed to load directory list at startup: %s", esp_err_to_name(disc_ret));
            }
        }
    }
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

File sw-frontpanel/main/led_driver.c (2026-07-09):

// SPDX-License-Identifier: GPL-2.0-only
//
//  Copyright (C) 2025  Ian Scott
//
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
#include "led_driver.h"
#include "led_strip.h"
#include "esp_log.h"
#include "freertos/FreeRTOS.h"
#include "freertos/task.h"
#include <math.h>

static const char *TAG = "led_driver";

static led_strip_handle_t led_strip = NULL;
static TaskHandle_t pulse_task_handle = NULL;
static bool pulse_running = false;
static rgb_color_t pulse_color;

// Last color set via led_set_color/led_set_rgb. The breathe task reads this
// every tick so the breathe color follows live state updates (e.g. the LED's
// "logical" color changing from cyan to orange while the screen is blanked).
static rgb_color_t cached_color = {0, 0, 0};
static TaskHandle_t breathe_task_handle = NULL;
static bool breathe_running = false;

#define BREATHE_CYCLE_MS 8000 // Full fade-down-and-back-up cycle
#define BREATHE_STEP_MS  20 // 50 fps
#define BREATHE_MIN 0.2f // Minimum brightness floor as a fraction of peak

// Predefined colors
const rgb_color_t COLOR_OFF =     {0,   0,  0};
const rgb_color_t COLOR_RED =     {32,  0,  0};
const rgb_color_t COLOR_GREEN =   {0,  32,  0};
const rgb_color_t COLOR_BLUE =    {0,   0, 32};
const rgb_color_t COLOR_WHITE =   {32, 32, 32};
const rgb_color_t COLOR_YELLOW =  {32, 32,  0};
const rgb_color_t COLOR_ORANGE =  {32,  6,  0};
const rgb_color_t COLOR_CYAN =    {0,  32, 32};
const rgb_color_t COLOR_MAGENTA = {32,  0, 32};

esp_err_t led_driver_init(void) {
    if (led_strip != NULL) {
        ESP_LOGW(TAG, "LED driver already initialized");
        return ESP_OK;
    }

    // LED strip general configuration
    led_strip_config_t strip_config = {
        .strip_gpio_num = LED_STRIP_GPIO_NUM,
        .max_leds = LED_STRIP_LED_COUNT,
        .led_model = LED_MODEL_WS2812,
        .color_component_format = LED_STRIP_COLOR_COMPONENT_FMT_GRB,
        .flags = {
            .invert_out = false,
        }
    };

    // LED strip RMT backend configuration
    led_strip_rmt_config_t rmt_config = {
        .clk_src = RMT_CLK_SRC_DEFAULT,
        .resolution_hz = LED_STRIP_RMT_RES_HZ,
        .mem_block_symbols = 64,
        .flags = {
            .with_dma = false,
        }
    };

    // Create LED strip object
    esp_err_t ret = led_strip_new_rmt_device(&strip_config, &rmt_config, &led_strip);
    if (ret != ESP_OK) {
        ESP_LOGE(TAG, "Failed to create LED strip: %s", esp_err_to_name(ret));
        return ret;
    }

    // Clear the LED strip (turn off)
    led_clear();

    ESP_LOGI(TAG, "LED driver initialized on GPIO%d with %d LEDs", 
             LED_STRIP_GPIO_NUM, LED_STRIP_LED_COUNT);
    
    return ESP_OK;
}

esp_err_t led_driver_deinit(void) {
    if (led_strip == NULL) {
        return ESP_OK;
    }

    // Clear LEDs before deinitializing
    led_clear();
    
    esp_err_t ret = led_strip_del(led_strip);
    led_strip = NULL;
    
    if (ret == ESP_OK) {
        ESP_LOGI(TAG, "LED driver deinitialized");
    } else {
        ESP_LOGE(TAG, "Failed to deinitialize LED driver: %s", esp_err_to_name(ret));
    }
    
    return ret;
}

esp_err_t led_set_color(rgb_color_t color) {
    return led_set_rgb(color.r, color.g, color.b);
}

esp_err_t led_set_rgb(uint8_t r, uint8_t g, uint8_t b) {
    if (led_strip == NULL) {
        ESP_LOGE(TAG, "LED driver not initialized");
        return ESP_ERR_INVALID_STATE;
    }

    cached_color.r = r;
    cached_color.g = g;
    cached_color.b = b;

    // While breathing, the breathe task drives the strip
    if (breathe_running) {
        return ESP_OK;
    }

    esp_err_t ret = led_strip_set_pixel(led_strip, 0, r, g, b);
    if (ret != ESP_OK) {
        ESP_LOGE(TAG, "Failed to set LED color: %s", esp_err_to_name(ret));
        return ret;
    }

    return led_refresh();
}

esp_err_t led_clear(void) {
    if (led_strip == NULL) {
        ESP_LOGE(TAG, "LED driver not initialized");
        return ESP_ERR_INVALID_STATE;
    }

    esp_err_t ret = led_strip_clear(led_strip);
    if (ret != ESP_OK) {
        ESP_LOGE(TAG, "Failed to clear LED strip: %s", esp_err_to_name(ret));
        return ret;
    }

    return led_refresh();
}

esp_err_t led_refresh(void) {
    if (led_strip == NULL) {
        ESP_LOGE(TAG, "LED driver not initialized");
        return ESP_ERR_INVALID_STATE;
    }

    esp_err_t ret = led_strip_refresh(led_strip);
    if (ret != ESP_OK) {
        ESP_LOGE(TAG, "Failed to refresh LED strip: %s", esp_err_to_name(ret));
    }

    return ret;
}

esp_err_t led_demo_rainbow(uint32_t duration_ms) {
    if (led_strip == NULL) {
        ESP_LOGE(TAG, "LED driver not initialized");
        return ESP_ERR_INVALID_STATE;
    }

    const uint32_t step_ms = 50;  // 50ms per color step
    const uint32_t steps = duration_ms / step_ms;
    
    ESP_LOGI(TAG, "Starting rainbow demo for %lu ms", duration_ms);

    for (uint32_t i = 0; i < steps; i++) {
        // Generate rainbow color using HSV to RGB conversion
        float hue = (float)(i * 360) / steps;  // 0-360 degrees
        float saturation = 1.0f;
        float value = 0.3f;  // Reduced brightness to avoid being too bright
        
        // Convert HSV to RGB
        float c = value * saturation;
        float x = c * (1 - fabsf(fmodf(hue / 60.0f, 2) - 1));
        float m = value - c;
        
        float r_prime, g_prime, b_prime;
        
        if (hue < 60) {
            r_prime = c; g_prime = x; b_prime = 0;
        } else if (hue < 120) {
            r_prime = x; g_prime = c; b_prime = 0;
        } else if (hue < 180) {
            r_prime = 0; g_prime = c; b_prime = x;
        } else if (hue < 240) {
            r_prime = 0; g_prime = x; b_prime = c;
        } else if (hue < 300) {
            r_prime = x; g_prime = 0; b_prime = c;
        } else {
            r_prime = c; g_prime = 0; b_prime = x;
        }
        
        uint8_t r = (uint8_t)((r_prime + m) * 255);
        uint8_t g = (uint8_t)((g_prime + m) * 255);
        uint8_t b = (uint8_t)((b_prime + m) * 255);
        
        esp_err_t ret = led_set_rgb(r, g, b);
        if (ret != ESP_OK) {
            ESP_LOGW(TAG, "Failed to set rainbow color at step %lu", i);
        }
        
        vTaskDelay(pdMS_TO_TICKS(step_ms));
    }

    // Turn off LED after demo
    led_clear();
    
    ESP_LOGI(TAG, "Rainbow demo completed");
    return ESP_OK;
}

esp_err_t led_flash_color(rgb_color_t color, uint32_t duration_ms) {
    if (led_strip == NULL) {
        ESP_LOGE(TAG, "LED driver not initialized");
        return ESP_ERR_INVALID_STATE;
    }

    ESP_LOGI(TAG, "Flashing color R:%d G:%d B:%d for %lu ms", 
             color.r, color.g, color.b, duration_ms);

    // Turn on
    esp_err_t ret = led_set_color(color);
    if (ret != ESP_OK) {
        return ret;
    }

    // Wait
    vTaskDelay(pdMS_TO_TICKS(duration_ms));

    // Turn off
    return led_clear();
}

// Activity indication functions
esp_err_t led_activity_read(void) {
    return led_set_color(COLOR_GREEN);
}
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

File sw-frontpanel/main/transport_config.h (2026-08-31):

// SPDX-License-Identifier: GPL-2.0-only
//
//  Copyright (C) 2025  Ian Scott
//
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
#ifndef TRANSPORT_CONFIG_H
#define TRANSPORT_CONFIG_H

// The transport is selected at runtime (transport_config_t.type), so both
// implementations' constants are defined unconditionally. Which transport a
// build actually uses is the Kconfig choice HOST_TRANSPORT: forced SPI or I2C,
// or AUTO (BlueSCSI) where the panel detects the link and persists it in NVS.

// Host communication settings
#define HOST_TIMEOUT_MS     1000       // Communication timeout in milliseconds

// I2C settings (BlueSCSI v2)
#define HOST_I2C_DEVICE_ADDR  0x50
#define HOST_I2C_CLOCK_SPEED  1000000  // 1 MHz (fast-mode-plus); needs good pull-ups
// Delay between header/write and read phases (lets the slave prepare its response).
// Busy-wait in microseconds; the slave prepares reads in its FINISH ISR, so this
// can be small. Too small -> master reads before the slave is ready.
#define I2C_INTER_PHASE_DELAY_US  200

// I2C link retries. A busy slave NACKs its address (the RP2040 slave does not
// clock-stretch), so a transient busy window surfaces as a NACK/timeout. Retry
// briefly to match SPI, where the master always clocks and readiness is handled
// by POLL_OP_READY.
#define I2C_RETRY_COUNT           3
#define I2C_RETRY_DELAY_US        200

// SPI settings (BlueSCSI Ultra/Ultra Wide, PicoIDE)
#define HOST_SPI_CLOCK_SPEED  10000000 // 10MHz (matches PicoIDE)
// Delay between header and payload phases
// No longer needed since IRQ handler debug prints are disabled by default on main board
#define SPI_INTER_PHASE_DELAY_US  0

// Startup delay: time to wait for main board to be ready before first comm attempt
#ifdef CONFIG_PRODUCT_BLUESCSI
#define HOST_STARTUP_DELAY_MS  2000
#else
#define HOST_STARTUP_DELAY_MS  1000
#endif

#endif // TRANSPORT_CONFIG_H

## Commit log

2025-08-26 Front panel proto fabbed at JLC 2025-08-26
    [BM04B-SRSS-TB.STEP, BM06B-SRSS-TB.STEP, BOM-frontpanel-3.5.csv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]
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2025-09-17 Working SPI communication between main board and front panel. I2C was working but now untested
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2025-09-18 Front panel board fabbed at JLCPCB 2025-09-17
    [AFC11-S12ICC-00.step, BM02B-SRSS-TB.STEP, BM04B-SRSS-TB.STEP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]
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2025-09-23 Working frontpanel firmware update from SD card via main board
    [partitions.csv]
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2025-10-07 Added the enclosure Step files and FreeCAD files.
    [PicoIDE 3.5 Enclosure - Cancel Button.step, PicoIDE 3.5 Enclosure - Enclosure.step, PicoIDE 3.5 Enclosure - Light Pipe.step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]
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2025-11-04 many changes made to the enclosure
    [PicoIDE 3.5 Enclosure - Cancel Button.step, PicoIDE 3.5 Enclosure - Enclosure.step, PicoIDE 3.5 Enclosure - Light Pipe.step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]
2025-11-14 added bluescsi holes made mounting holes smaller added internal mounting holes made the picoide logo it's own object
    [PicoIDE 3.5 Enclosure.FCStd, PicoIDE 3.5 Enclosure.step, PicoIDE 3.5 Enclosure.stl]
2025-11-14 fixed corrupt file error
    [PicoIDE 3.5 Enclosure.FCStd]
2025-11-18 added silicone buttons
    [PicoIDE 3.5 Enclosure-Silicone Buttons.step, PicoIDE 3.5 Enclosure-Silicone Buttons.stl, PicoIDE 3.5 Enclosure.FCStd]
2025-11-18 added exhaust channels to silicone buttons
    [PicoIDE 3.5 Enclosure-Silicone Buttons.step, PicoIDE 3.5 Enclosure-Silicone Buttons.stl, PicoIDE 3.5 Enclosure.FCStd]
2025-11-21 tweaked for molding feedback and added second logo plate
    [PicoIDE 3.5 Enclosure-Silicone Buttons.step, PicoIDE 3.5 Enclosure-Silicone Buttons.stl, PicoIDE 3.5 Enclosure.FCStd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]
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2025-11-29 Use RC for ESP32 reset, power on reset for OLED
    [frontpanel-3.5.kicad_pcb, frontpanel-3.5.kicad_sch]
2025-11-29 Provisional v1.0.0 hardware
    [BOM-frontpanel-3.5.csv, frontpanel-3.5.kicad_pcb, frontpanel-3.5.kicad_sch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]
2025-12-23 Final candidate v1.0.0 hardware
    [frontpanel-3.5.kicad_pcb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]
2025-12-31 Final v1.0.0 front panel design
    [frontpanel-3.5.kicad_pcb, frontpanel-3.5.kicad_sch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]
2026-01-04 modular faceplate made better and added steps and stls
    [BlueSCSI 3.5 Enclosure.step, BlueSCSI 3.5 Enclosure.stl, PicoIDE 3.5 Enclosure.FCStd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]
2026-01-08 Better handling of image status, handle fixed HDDs on status screen
    [led_driver.c, main.c]
2026-01-08 Fix for keypress to wake up display passing through as event
    [main.c]
2026-01-08 Fix display glitch on firmware update screen
    [main.c]
2026-01-11 Make front panel firmware check more in line with main board firmware check
2026-01-30 added the bluescsi screw adapter and moved the front screw boss back based on molding feedback
    [BlueSCSI 3.5 Enclosure.step, BlueSCSI 3.5 Enclosure.stl, BlueSCSI Screw Adapter.step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]
2026-01-30 added stl for bluescsi screw adapter
    [BlueSCSI Screw Adapter.stl]
2026-02-03 final changes (hopefully) for molding
    [BlueSCSI 3.5 Enclosure.step, BlueSCSI 3.5 Enclosure.stl, BlueSCSI Screw Adapter.step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]
2026-02-08 more tweaks
    [BlueSCSI 3.5 Enclosure.step, BlueSCSI 3.5 Enclosure.stl, PicoIDE 3.5 Enclosure.FCStd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]
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2026-02-19 fixup bluescsi fw version string as date
    [main.c, transport_config.h]
2026-02-19 Collapse WiFi config section when already connected Check BlueSCSI GitHub releases for main board update availability Show free memory in KB, uptime as min:sec Disable spellcheck on config editor Cou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
2026-02-27 made holes bigger for buttons so silicone buttons don't stick anymore.
    [BlueSCSI 3.5 Enclosure.step, BlueSCSI 3.5 Enclosure.stl, PicoIDE 3.5 Enclosure.FCStd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]
2026-05-31 Correctly report main/panel firmware versions in web interface
    [web_server.cpp]
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2026-06-01 Use "liveness magic" on PicoIDE to better determine if main board is alive
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2026-06-05 Add direct firmware upload to ESP32 front panel
    For BlueSCSI, make the direct upload the primary panel-update path.
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2026-06-05 Hide Prev/Next image buttons on BlueSCSI web UI
    Currently we just eject to cycle or select from UI. May add prev later.
2026-06-08 Implement I2C transport async polling
    Implement transport_i2c_poll_async_status() (mirroring the SPI path) and
    move the POLL_OP_READY ready/result read out of two_phase_transaction.
    Guard transport_poll_async_status against a NULL op so a transport that
    does not implement it returns ESP_ERR_NOT_SUPPORTED instead of crashing.
    Add an I2C inter-phase delay knob.
    [transport_config.h, transport_i2c.c]
2026-06-08 Add bluescsi-v2 (I2C) front-panel build variant
    Make the host transport a Kconfig choice (HOST_TRANSPORT_SPI/_I2C),
    orthogonal to product and selected per-build via sdkconfig.defaults.i2c.
    BlueSCSI Ultra and PicoIDE keep SPI; BlueSCSI v2 uses I2C and builds as
    bluescsi-v2-frontpanel.bin. Update BUILD.md and the CI matrix.
2026-06-09 Bump panel I2C to 1 MHz and shrink the inter-phase delay
    Raise the I2C host clock from 400 kHz to 1 MHz (fast-mode-plus) and drop the
    header-to-read inter-phase delay from 1 ms to 200 us, using esp_rom_delay_us()
    for real microsecond granularity (vTaskDelay only resolves milliseconds). The
    slave prepares its read response in the ISR, so the long delay was unnecessary.
    [transport_config.h, transport_i2c.c]
2026-06-09 Add host-native unit tests for the protocol and host-comm layer
    Compile host_comm.c and transport.c against ESP-IDF/FreeRTOS stubs and a
    recording mock transport, covering the panel_protocol_defs.h wire contract
    (struct packing, command bits) and host_comm command framing. Runs as the
    host-tests CI job; needs only host gcc + make.
2026-06-09 Quiet per-transaction I2C transport logging
    Drop the phase-by-phase ESP_LOGD traces and payload hex dump from the
    I2C transport hot path, and move file-op result codes to debug level.
    Errors and operation-start logs are unchanged.
    [transport_i2c.c]
2026-06-09 Retry NACKed I2C transactions and fold file ops onto one path-op helper
    A busy I2C slave NACKs its address (no clock stretching on the RP2040
    side), which previously surfaced as an immediate error; retry the
    transaction up to I2C_RETRY_COUNT times so transient busy windows behave
    like SPI, where the master always clocks and readiness is handled by
    POLL_OP_READY. Also collapse delete/rename/touch/mkdir onto a single
    host_comm_path_op helper (same wire format) and drop the unused
    I2C/SPI_MAX_TRANSFER defines.
    [transport_config.h, transport_i2c.c]
2026-06-09 Name the BlueSCSI SPI firmware bluescsi-ultra and release all variant bins
    bluescsi-frontpanel.bin was ambiguous next to bluescsi-v2-frontpanel.bin;
    name each image after the host board it pairs with (Ultra/Ultra Wide vs
    v2) so users can pick the right file. Also attach the two BlueSCSI bins
    to GitHub releases, which previously shipped only the PicoIDE image.
2026-06-10 updated the bluescsi 3.5 enclosure
    [BlueSCSI 3.5 Enclosure.step, BlueSCSI 3.5 Enclosure.stl, PicoIDE 3.5 Enclosure.FCStd]
2026-06-11 added supports for bosses
    [BlueSCSI 3.5 Enclosure.step, BlueSCSI 3.5 Enclosure.stl, PicoIDE 3.5 Enclosure.FCStd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]
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2026-07-06 added a ramp to make printing the back easier
    [BlueSCSI 3.5 Enclosure.step, BlueSCSI 3.5 Enclosure.stl, PicoIDE 3.5 Enclosure.FCStd]
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2026-08-03 Fix disc browser off-by-one when host injects its own ".."
    The disc browser derived the host directory-entry index from the menu
    row position (selected - 1). That assumes menu rows map 1:1 to host
    entries, but refresh_directory_list() prepends its own ".." and then
    skips the host's own "." / ".." entries. On BlueSCSI the main board
    injects a ".." at index 0 in every non-root directory, so after the
    skip every row was off by one: selecting an image loaded the entry
    above it, and near the top of a folder it sent a directory index,
    which made the host navigate/unmount the disc (spurious "TRAY OPEN").
    Root directories (no "..") mapped 1:1, which is why it looked
    intermittent.
    Carry the host's r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
    [main.c]
2026-08-03 Send the parent-dir sentinel from the no-entries fallback row
    The "No entries available" row (host entry-count fetch failed) never got
    an entry_index, so it kept menu_item_t's calloc default of 0. Selection
    sends host_comm_select_entry() before the is_directory branch, so
    pressing select on that row sent SELECT_ENTRY(0) instead of the -1 the
    row-derived index used to produce. In a non-root directory entry 0 is the
    host's injected "..", but in the root it is a real file — a transient
    comm error followed by a button press loaded an image the user never
    picked.
    [main.c]
2026-08-03 Reject use of an uninitialised host_comm and harden the alive probe
    Twelve entry points checked only for a NULL pointer before HOST_COMM_LOCK,
    so a torn-down handle meant xSemaphoreTake(NULL) - configASSERT abort, or
    a NULL deref with assertions off. Check initialized too.
    Repeating the alive-magic read is not an independent sample: a floating
    input settles to a level set by leakage and coupling, so a bus clocking in
    a uniform 0xA5 reproduces it on every probe and passes a one-byte check.
    Reject a response whose bytes are all identical, and range-check the
    boolean fields, which the main board only ever writes as 0 or 1.
    host_comm_deinit no longer returns early when transport_deinit fails: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
2026-08-03 Probe for the main board without tearing down the shared handle
    establish_host_link() called host_comm_deinit() on the shared host_comm
    after every failed probe, which deletes its mutex and leaves it NULL, and
    the web server starts even when detection times out. Clicking prev/next
    image then panicked the panel - the normal outcome for a USB-powered panel
    with the board off. Probe on the scratch handle and only bring up the
    shared one on success, the discipline status_refresh_task already used.
    The background probe now runs before the display-state gate, so a blanked
    screen (idle blanking is on by default) no longer stops the panel from
    noticing a board powered on later, and it backs off 1s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
    [main.c]
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2026-08-17 Styling fixes
    - PicoIDE logo was too wide on phones
    - Load button was too small
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2026-08-31 Fix the multi-device regressions that reached main in PR #14
    PR #14 made every device-specific request name its device explicitly, which
    is right, but four defects rode along and they all land on BlueSCSI.
    The web file browser went blank and stayed blank whenever /api/devices came
    back empty. refreshImages() bailed on a null device, nothing re-polled the
    device list, and the Refresh button only reloaded the device strip. BlueSCSI
    reports zero devices by design while it is imaging in initiator mode, and
    reports none at all when the device-list command fails, so a card full of
    files became unbrowsable. Browsing is a read: /api/images now falls back to
    the panel's own active device and echoes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
    [main.c, test_host_comm.c]
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2026-08-31 panel: read initiator progress from its own status command
    The imaging screen had nothing to draw. GET_INITIATOR_STATUS is async and an
    imaging board never completes it, so phase stayed idle and the panel sat on the
    splash. Poll PANEL_CMD_GET_INITIATOR_SUMMARY instead - a synchronous read the
    main board answers from its ISR - and draw the screen from that. The async
    per-target detail is still fetched, but the screen no longer depends on it: the
    imaging phase renders a real progress bar from the summary when the detail is
    absent, rather than an "Imaging..." placeholder.
    The two modes stay in their own responses. The playback status keeps its
    target-mode shape and gains only what is neither m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
    [main.c, test_host_comm.c]
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2026-09-02 chore: release 0.5.0
    Also fix the release jobs, which were skipped on the first 0.5.0 tag: a
    job whose `if` has no status function still has to pass an implicit
    success() over its whole ancestor chain, and bump-version is skipped on
    tag pushes. Both release jobs now check the build's result directly.
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2026-09-03 Make the initiator screens build and print with nano printf
    refactor format_size() to use 32-bit instead of 64-bit ints to avoid
    %llu which is unsupported by nano printf. Will overflow at 4TB, though.
    Fix initiator_fit_filename() causing errors with -Werror=format-truncation by
    using strlcpy instead of snprintf("%s").
2026-09-19 fix: upload errors reported as "Network error" in the browser
    Responding to an upload before the body is read closes the socket, so the
    browser never reads the message. Drain the request first.
    [web_server.cpp]
2026-09-29 Speed up web UI load over WiFi
    - Don't tear down mDNS on every Wifi state change - mDNS automatically handles that
    - Serve static assets with a per-build ETag and Cache-Control: no-cache for effectively infinite cache lifetime
    - Issue startup fetches in parallel and bump max_open_sockets
    [web_server.cpp]
2026-10-01 AP & hostname config (#29)
    * Allow AP SSID and hostname to be configured
    * Show hostname on WiFi status screen and make info screens scrollable
    * Use a random per-device default AP password in PicoIDE mode
    * Allow AP password to be set
    * Compact WiFi settings screen
    * Escape control characters in JSON
    * DRY up scrollbar drawing
    * Better error handling
    * Use strlcpy for plain string copies
    * Keep the default AP password in ap_default_pw for both products
    * Save each WiFi setting on its own, and check for NVS errors
    This prevents an issue where saving AP or hostname settings would
    also save station credentials from a failed connection.
    * Don't store default WiFi settings
    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
    [main.c, web_server.cpp, wifi_manager.h]
2026-10-01 fix: size the httpd handler table from uri_handlers[]. the bench build overflowed the fixed limit after /api/settings.
    [web_server.cpp]
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

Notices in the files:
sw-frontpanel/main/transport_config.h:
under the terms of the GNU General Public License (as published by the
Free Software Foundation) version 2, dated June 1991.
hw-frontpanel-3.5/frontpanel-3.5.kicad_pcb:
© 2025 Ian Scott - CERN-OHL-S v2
